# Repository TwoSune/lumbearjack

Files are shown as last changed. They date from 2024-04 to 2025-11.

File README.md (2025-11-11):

# Lumbearjack - Ortholinear 60% PCB based on Lumberjack by peej

Lumbearjack is a revision of peej's lumberjack with the following features:
* Pro Micro style controller support
* Per-key RGB and Backlight support
* Rotary encoder support
* SMD diode support
* BSS138 logic level shifter
  
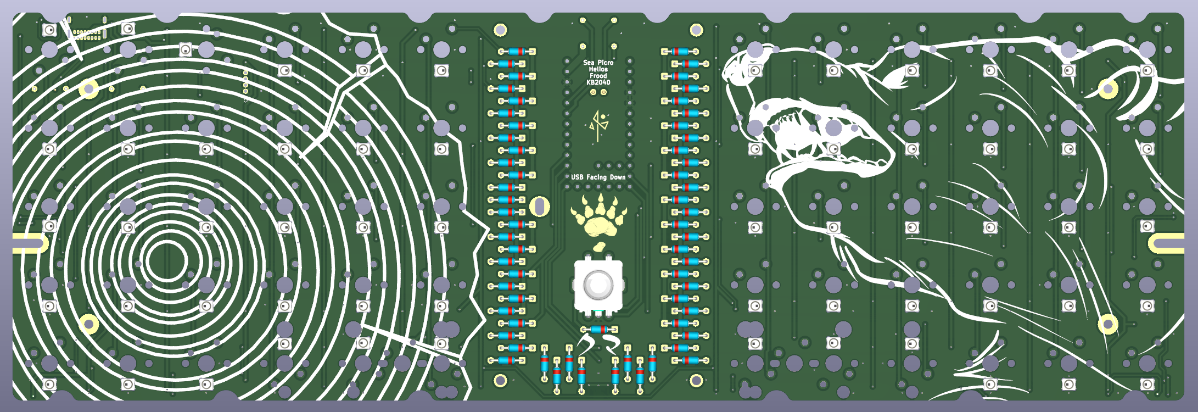
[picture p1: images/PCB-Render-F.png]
PCB Render Front

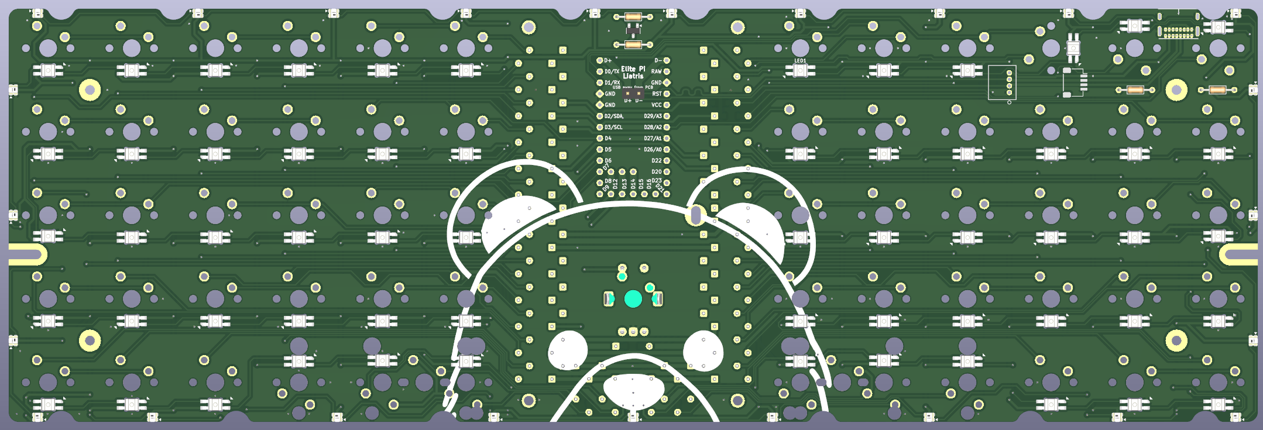
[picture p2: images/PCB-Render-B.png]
PCB Render Back


Lumbearjack is currently designed for the following development boards:
* Helios
* Sea Picro
* Frood
* KB2040 (no encoder support)
  
With support for the following, but you may struggle with external USB data lines
* Liatris
* Elite-Pi

At its core, Lumbearjack remains easy to build with minimal soldering experience, but being familiar with soldering is highly recommended for per-key RGB (SK68XX Mini-E) and backlight (WS2812B 2020).

Build Example
PCB Picture
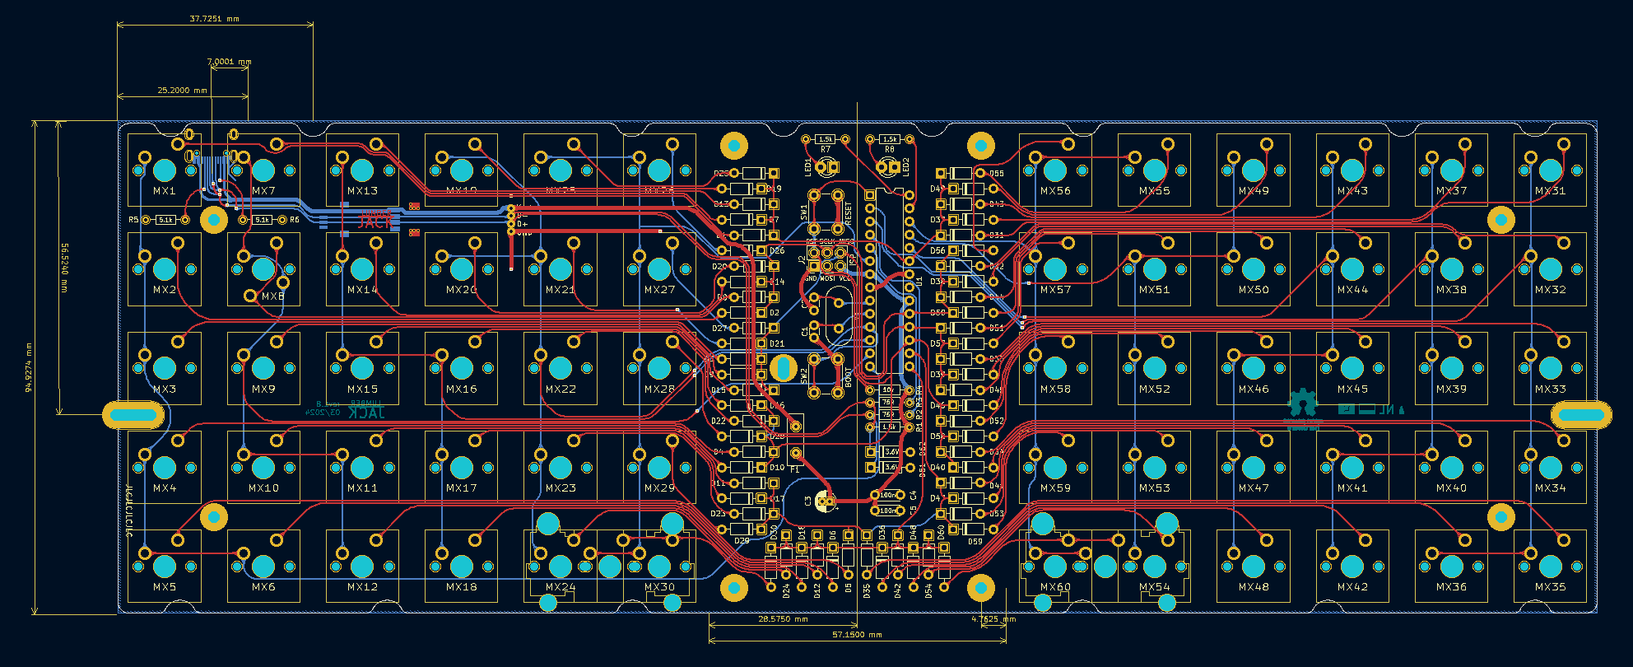
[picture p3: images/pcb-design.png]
PCB design


# Ordering parts

See the [Bill of materials](BOM.md) for a detailed list of the required parts.

BOM

PCBs can be manufactuered by a variety of online PCB fabricators. You can use [PCBShopper](https://pcbshopper.com/) to search for the best price.

The [zip file in the gerber directory](https://github.com/peej/lumberjack-keyboard/blob/master/gerber/lumberjack.zip) contains the gerber files your fabricator will need to make the PCB.

When uploading the gerber zip files, use the default PCB settings.

If you want to use a plate, there are [gerbers for FR4 plates](https://github.com/peej/lumberjack-keyboard/tree/smd-usbc/plates/gerbers). For the split plate, you will need two plates, one for each half of the keyboard.

# Construction

First, solder all the diodes on the top of the board. If you do not plan on using an encoder or a switch in the middle, you may omit the diode in the center of the board.
After you solder the diodes, solder the USB port on your board. From there, you may decide whether you would like to solder the LEDs or the controller to your board. It is recommended to solder the controller first so you may test your RGB as you solder them a few at a time.

See [the build guide](guide.md) for more information.

## Need help?

Feel free to create an issue request or contact me via discord at xsune for help!

# Firmware

Firmware is available in my [firmware repository](hyperlink)

Follow the [QMK firmware instructions](https://docs.qmk.fm/#/flashing) to build and flash the firmware.

(as of Rev 1.0, there is no onboard reset button. A reset button will be added to Rev 1.1.) 

## VIAL

Lumbearjack is compatible with Vial. You may follow the instructions for setting up a build environment [here](https://get.vial.today)
ZMK firmware will be added in the future

## Bootloader

 [See the build guide for more information](guide.md#bootloader).

## Matrix information

If you are building your own firmware, the following matrix information will be useful to you:

| Configuration | Value |
|---|---|
| MATRIX_ROWS | 12 |
| MATRIX_COLS | 7 |
| MATRIX_ROW_PINS | X (GPX), X (GPX), X (GPX), X (GPX), X (GPX), |
| MATRIX_COL_PINS | X (GPX), X (GPX), X (GPX), X (GPX), X (GPX), |
| DIODE_DIRECTION | COL2ROW |

Lumbearjack uses an interleaved matrix to save a pin for RGB and a pin for the middle key so KB2040 users may still have access to most of the features. You must use an Elite-C style dev board for encoder support.

Layout pins
# Component cover

Cut a piece of 2mm thick acrylic to size (95x57mm) and drill 4 m2 holes in the corners for the standoffs. Use the PCB or cover.dxf as a guide for the hole positions, you can also use cover.dxf for laser cutting the correct size acrylic.

Affix the 4 standoffs to the PCB with screws from underneath the PCB. Use the remaining 4 screws to attach the acrylic to the top of the standoffs.

Completed build w/o caps

# Revisions

## Rev 1.0

* Initial design introduced

## Rev 1.1 plans:
* Make external USB data lines easier to solder for Elite-Pi and Liatris users.
* RGB strip support
* Adjust some LED placements and switch orientations
* Add Reset Button
* Possibly revise the logic level shifter

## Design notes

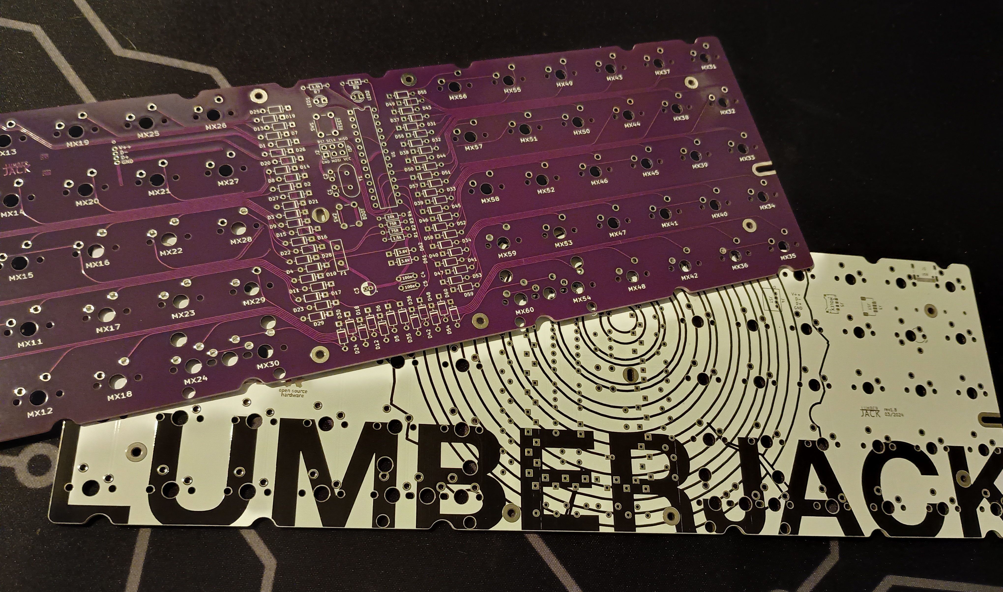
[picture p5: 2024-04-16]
images/pcb.jpg

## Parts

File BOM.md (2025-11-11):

# Bill of Materials (BOM)

| Ref | Qty | Value or Part# | Description |
|---|---|---|---|
| ![U1]() | 0-1 | Helios/n!n | Helios or similar controller with external USB |
| ![D1-61]() | 60-61 | 1N4148 | generic switching diode |
| ![MX1-61]() | 60-61 | MX Switch | Cherry MX-compatible keyboard switch |
| ![SW2]() | 0-1 | EC11 | EC11 rotary encoder (optional, instead of switch #61) |
| ![LED1-60]() | 60 | SK68XX MINI-E  | Per-key RGB (optional) |
| ![LED61-85]()  | 25 | WS2812 2020 | Backlight (optional) |
| ![LED61-85]()  | 25 | WS2812 Strip | Backlight (optional) |
| ![J1]() | 1 | USB4085-GF-A | USB-C socket (only used with the Frood controller) |
| ![J3]() | 1 | SM04B-SRSS-TB  | JST SH SMD socket, 1.5 mm pitch (optional for daughterboard) |
| ![J4]() | 1 | S4B-ZR | JST ZH right-angle THT socket, 1.5 mm pitch (optional for daughterboard) |
| ![R1, R2]() | 2 | 10 kΩ | 1/8 W resistor (For BSS138 Logic Level shifter) |
| ![R5, R6]() | 2 | 5.1 kΩ | 1/8 W resistor (only needed for USB-C) |
| ![SW1]() | 1 | 6x3 mm | tactile micro switch |
| ![cover]() | 1 | 95x57x3 mm | 3 mm acrylic component cover |
| ![screw]() | 8 | M2x4 mm | screws to mount the cover |
| ![standoff]()  | 4 | M2x10 mm | standoffs for component cover |

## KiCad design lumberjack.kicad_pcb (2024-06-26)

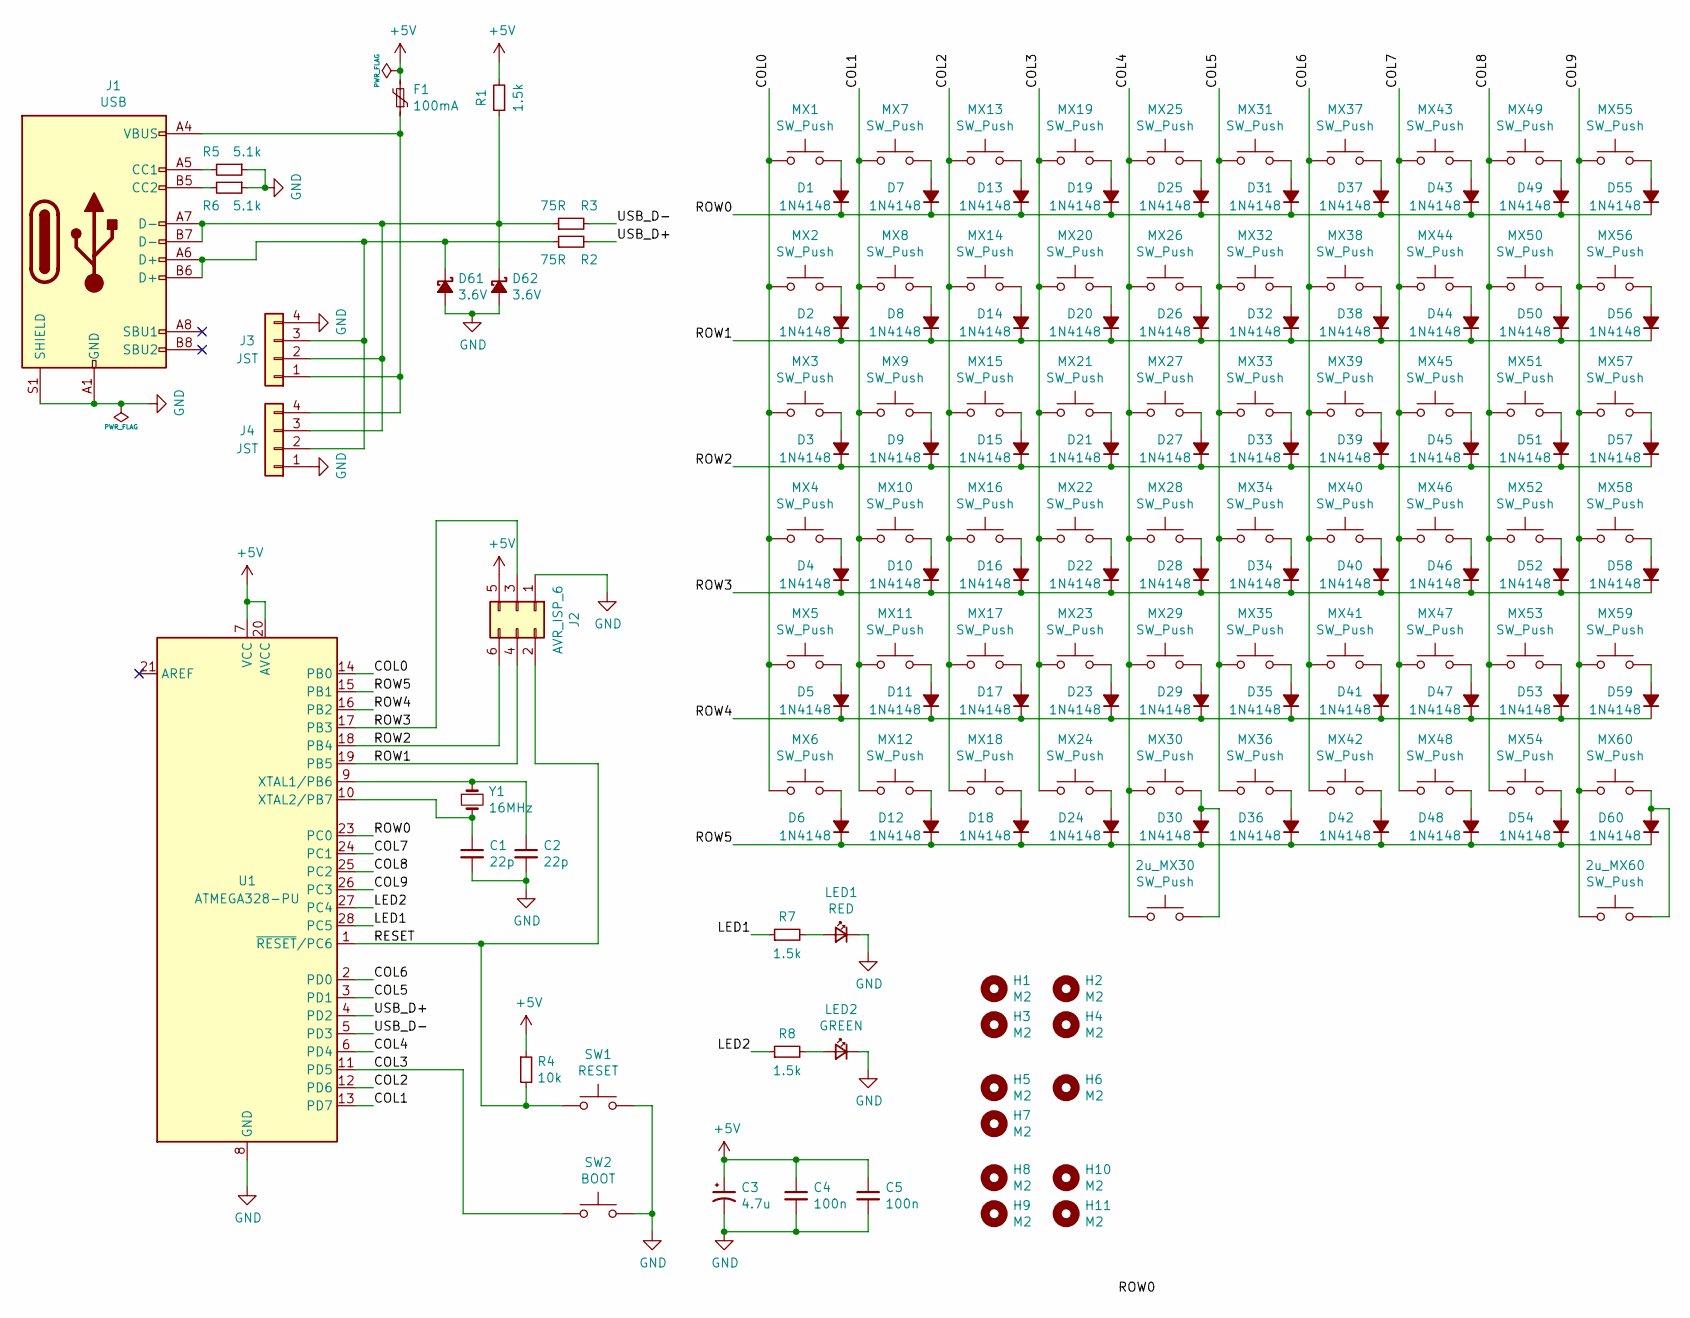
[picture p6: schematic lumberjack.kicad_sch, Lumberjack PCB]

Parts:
2u_MX30, 2u_MX60: SW_Push; MX_PCB_200B
C1, C2: 22p; C_Disc_D3.0mm_W1.6mm_P2.50mm
C3: 4.7u; CP_Radial_D4.0mm_P1.50mm
C4, C5: 100n; C_Disc_D4.3mm_W1.9mm_P5.00mm
D1, D2, D3, D4, D5, D6, D7, D8, D9, D10, D11, D12, D13, D14, D15, D16, D17, D18, D19, D20, D21, D22, D23, D24, D25, D26, D27, D28, D29, D30, D31, D32, D33, D34, D35, D36, D37, D38, D39, D40, D41, D42, D43, D44, D45, D46, D47, D48, D49, D50, D51, D52, D53, D54, D55, D56, D57, D58, D59, D60: 1N4148; D_DO-35_SOD27_P7.62mm_Horizontal
D61, D62: 3.6V; D_DO-35_SOD27_P7.62mm_Horizontal
F1: 100mA; Fuse_Bourns_MF-RHT100
H1, H2, H3, H4, H8, H9, H10, H11: M2; MountingHole_M2
H5, H6, H7: M2; MountingSlot_M2
J1: USB; TYPE-C-31-M-12
J2: AVR_ISP_6; PinHeader_2x03_P2.54mm_Vertical
J3: JST; JST_SH_SM04B-SRSS-TB_1x04-1MP_P1.00mm_Horizontal
J4: JST; S4B-ZRLFSN
LED1: RED; LED_D3.0mm
LED2: GREEN; LED_D3.0mm
MX1, MX2, MX3, MX4, MX5, MX6, MX7, MX9, MX10, MX11, MX12, MX13, MX14, MX15, MX16, MX17, MX18, MX19, MX20, MX21, MX22, MX23, MX24, MX25, MX26, MX27, MX28, MX29, MX30, MX31, MX32, MX33, MX34, MX35, MX36, MX37, MX38, MX39, MX40, MX41, MX42, MX43, MX44, MX45, MX46, MX47, MX48, MX49, MX50, MX51, MX52, MX53, MX54, MX55, MX56, MX57, MX58, MX59, MX60: SW_Push; MX_Alps_Choc
MX8: SW_Push; MX_Alps_Choc_NTHSTH
R1, R7, R8: 1.5k; R_Axial_DIN0204_L3.6mm_D1.6mm_P7.62mm_Horizontal
R2, R3: 75R; R_Axial_DIN0204_L3.6mm_D1.6mm_P7.62mm_Horizontal
R4: 10k; R_Axial_DIN0204_L3.6mm_D1.6mm_P7.62mm_Horizontal
R5, R6: 5.1k; R_Axial_DIN0204_L3.6mm_D1.6mm_P7.62mm_Horizontal
SW1: RESET; SW_PUSH_6mm
SW2: BOOT; SW_PUSH_6mm
U1: ATMEGA328-PU; DIP-28_W7.62mm
Y1: 16MHz; Crystal_HC49-4H_Vertical

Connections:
+5V: C3.1, C4.1, C5.1, F1.2, J2.5, R1.2, R4.1, U1.7 (VCC), U1.20 (AVCC)
/COL0: MX1.2, MX2.2, MX3.2, MX4.2, MX5.2, MX6.2, U1.14 (PB0)
/COL1: MX7.2, MX8.2, MX9.2, MX10.2, MX11.2, MX12.2, U1.13 (PD7)
/COL2: MX13.2, MX14.2, MX15.2, MX16.2, MX17.2, MX18.2, U1.12 (PD6)
/COL3: MX19.2, MX20.2, MX21.2, MX22.2, MX23.2, MX24.2, SW2.1, U1.11 (PD5)
/COL4: 2u_MX30.2, MX25.2, MX26.2, MX27.2, MX28.2, MX29.2, MX30.2, U1.6 (PD4)
/COL5: MX31.2, MX32.2, MX33.2, MX34.2, MX35.2, MX36.2, U1.3 (PD1)
/COL6: MX37.2, MX38.2, MX39.2, MX40.2, MX41.2, MX42.2, U1.2 (PD0)
/COL7: MX43.2, MX44.2, MX45.2, MX46.2, MX47.2, MX48.2, U1.24 (PC1)
/COL8: MX49.2, MX50.2, MX51.2, MX52.2, MX53.2, MX54.2, U1.25 (PC2)
/COL9: 2u_MX60.2, MX55.2, MX56.2, MX57.2, MX58.2, MX59.2, MX60.2, U1.26 (PC3)
/LED1: R7.1, U1.28 (PC5)
/LED2: R8.1, U1.27 (PC4)
/RESET: J2.2, R4.2, SW1.1, U1.1 (~RESET/PC6)
/ROW0: D1.1 (K), D7.1 (K), D13.1 (K), D19.1 (K), D25.1 (K), D31.1 (K), D37.1 (K), D43.1 (K), D49.1 (K), D55.1 (K), U1.23 (PC0)
/ROW1: D2.1 (K), D8.1 (K), D14.1 (K), D20.1 (K), D26.1 (K), D32.1 (K), D38.1 (K), D44.1 (K), D50.1 (K), D56.1 (K), J2.4, U1.19 (PB5)
/ROW2: D3.1 (K), D9.1 (K), D15.1 (K), D21.1 (K), D27.1 (K), D33.1 (K), D39.1 (K), D45.1 (K), D51.1 (K), D57.1 (K), J2.6, U1.18 (PB4)
/ROW3: D4.1 (K), D10.1 (K), D16.1 (K), D22.1 (K), D28.1 (K), D34.1 (K), D40.1 (K), D46.1 (K), D52.1 (K), D58.1 (K), J2.3, U1.17 (PB3)
/ROW4: D5.1 (K), D11.1 (K), D17.1 (K), D23.1 (K), D29.1 (K), D35.1 (K), D41.1 (K), D47.1 (K), D53.1 (K), D59.1 (K), U1.16 (PB2)
/ROW5: D6.1 (K), D12.1 (K), D18.1 (K), D24.1 (K), D30.1 (K), D36.1 (K), D42.1 (K), D48.1 (K), D54.1 (K), D60.1 (K), U1.15 (PB1)
/USB_D+: R2.2, U1.4 (PD2)
/USB_D-: R3.2, U1.5 (PD3)
GND: C1.2, C2.2, C3.2, C4.2, C5.2, D61.2 (A), D62.2 (A), J1.A1 (GND), J1.A12 (GND), J1.B1 (GND), J1.B12 (GND), J1.S1 (SHIELD), J2.1, J3.4, J4.1, LED1.1 (K), LED2.1 (K), R5.1, R6.1, SW1.2, SW2.2, U1.8 (GND), U1.22 (GND); also elsewhere on the board
unnamed: D1.2 (A), MX1.1
unnamed: D2.2 (A), MX2.1
unnamed: D3.2 (A), MX3.1
unnamed: D4.2 (A), MX4.1
unnamed: D5.2 (A), MX5.1
unnamed: D6.2 (A), MX6.1
unnamed: D7.2 (A), MX7.1
unnamed: D8.2 (A), MX8.1
unnamed: D9.2 (A), MX9.1
unnamed: D10.2 (A), MX10.1
unnamed: D11.2 (A), MX11.1
unnamed: D12.2 (A), MX12.1
unnamed: D13.2 (A), MX13.1
unnamed: D14.2 (A), MX14.1
unnamed: D15.2 (A), MX15.1
unnamed: D16.2 (A), MX16.1
unnamed: D17.2 (A), MX17.1
unnamed: D18.2 (A), MX18.1
unnamed: D19.2 (A), MX19.1
unnamed: D20.2 (A), MX20.1
unnamed: D21.2 (A), MX21.1
unnamed: D22.2 (A), MX22.1
unnamed: D23.2 (A), MX23.1
unnamed: D24.2 (A), MX24.1
unnamed: D25.2 (A), MX25.1
unnamed: D26.2 (A), MX26.1
unnamed: D27.2 (A), MX27.1
unnamed: D28.2 (A), MX28.1
unnamed: D29.2 (A), MX29.1
unnamed: 2u_MX30.1, D30.2 (A), MX30.1
unnamed: D31.2 (A), MX31.1
unnamed: D32.2 (A), MX32.1
unnamed: D33.2 (A), MX33.1
unnamed: D34.2 (A), MX34.1
unnamed: D35.2 (A), MX35.1
unnamed: D36.2 (A), MX36.1
unnamed: D37.2 (A), MX37.1
unnamed: D38.2 (A), MX38.1
unnamed: D39.2 (A), MX39.1
unnamed: D40.2 (A), MX40.1
unnamed: D41.2 (A), MX41.1
unnamed: D42.2 (A), MX42.1
unnamed: D43.2 (A), MX43.1
unnamed: D44.2 (A), MX44.1
unnamed: D45.2 (A), MX45.1
unnamed: D46.2 (A), MX46.1
unnamed: D47.2 (A), MX47.1
unnamed: D48.2 (A), MX48.1
unnamed: D49.2 (A), MX49.1
unnamed: D50.2 (A), MX50.1
unnamed: D51.2 (A), MX51.1
unnamed: D52.2 (A), MX52.1
unnamed: D53.2 (A), MX53.1
unnamed: D54.2 (A), MX54.1
unnamed: D55.2 (A), MX55.1
unnamed: D56.2 (A), MX56.1
unnamed: D57.2 (A), MX57.1
unnamed: D58.2 (A), MX58.1
unnamed: D59.2 (A), MX59.1
unnamed: 2u_MX60.1, D60.2 (A), MX60.1
unnamed 83: D61.1 (K), J1.A6 (D+), J1.B6 (D+), J3.3, J4.2, R2.1; also elsewhere on the board
unnamed 84: D62.1 (K), J1.A7 (D-), J1.B7 (D-), J3.2, J4.3, R1.1, R3.1; also elsewhere on the board
unnamed: J1.A5 (CC1), R5.2
unnamed: J1.B5 (CC2), R6.2
unnamed 87: F1.1, J1.A4 (VBUS), J1.A9 (VBUS), J1.B4 (VBUS), J1.B9 (VBUS), J3.1, J4.4; also elsewhere on the board
unnamed: LED1.2 (A), R7.2
unnamed: LED2.2 (A), R8.2
unnamed: C2.1, U1.9 (XTAL1/PB6), Y1.1
unnamed: C1.1, U1.10 (XTAL2/PB7), Y1.2

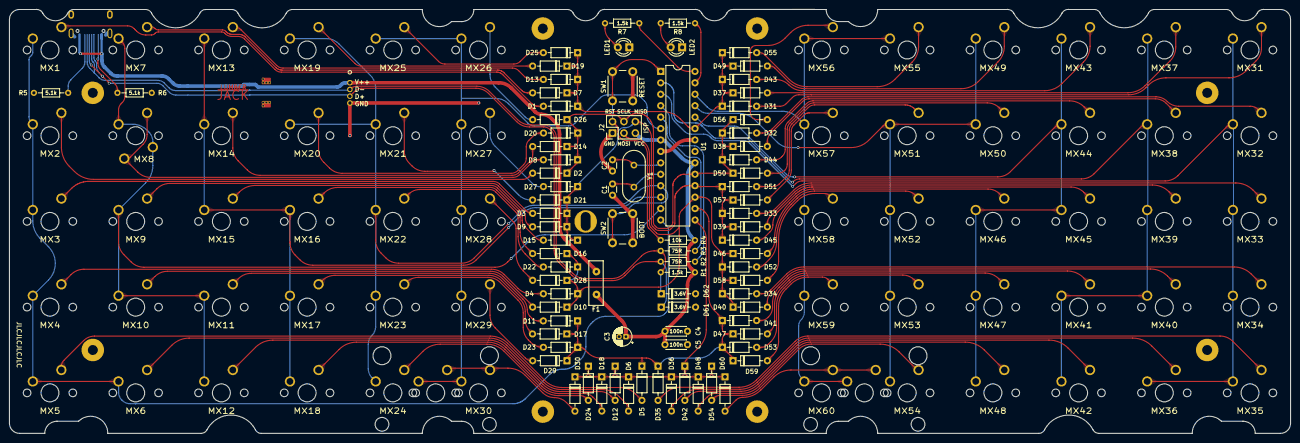
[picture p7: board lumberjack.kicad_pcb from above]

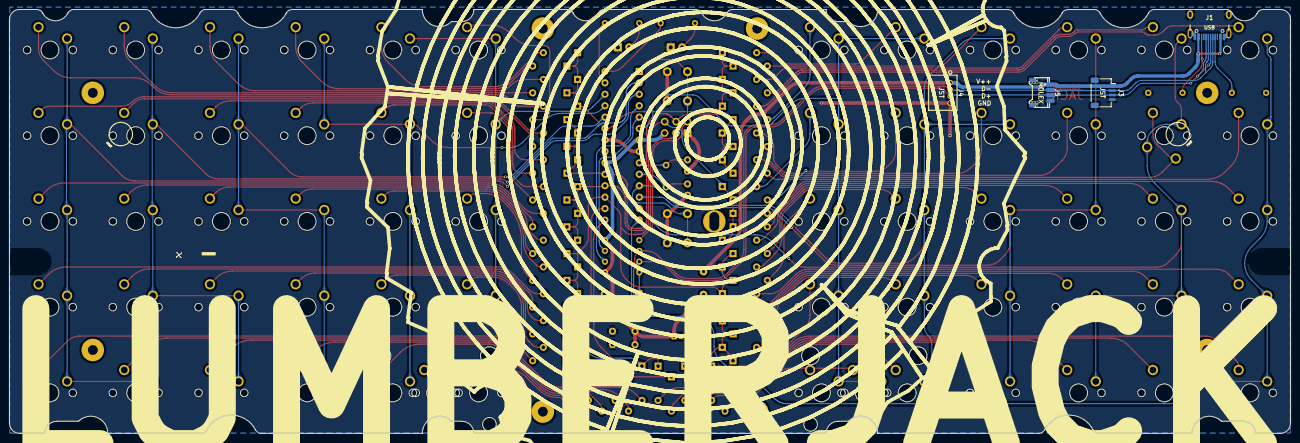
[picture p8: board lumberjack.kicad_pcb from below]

Board: 2 copper layers, 284.7 x 94.2 mm, 160 parts (4 on the bottom side), 92 nets.

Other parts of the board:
J5: Molex; PicoEZMate-Reinforced-Lite

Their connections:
GND: J5.4; also elsewhere on the board
unnamed 83: J5.3; also elsewhere on the board
unnamed 84: J5.2; also elsewhere on the board
unnamed 87: J5.1; also elsewhere on the board

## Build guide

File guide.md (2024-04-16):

# Lumberjack - Kit assembly guide

This assembly guide will guide you through putting together your Lumberjack keyboard PCB kit. The process is quite simple with only basic soldering experience.

## Before starting

* Check you have all the required items not included in the kit.
    * Soldering iron
    * Solder
    * Flush cutters
    * 60 MX key switches
* Check that you have all the components. See [BOM](BOM.md)
    * Keep the resistors in the paper reel so that it is easy to tell them apart based upon how many there are.
    * Do not confuse the 2 zener diodes with the 60 1N4148 diodes, they look almost identical but perform quite different functions.
* If you are not used to soldering, learn how to solder components.
    * https://learn.adafruit.com/adafruit-guide-excellent-soldering/tools

## Soldering

### USB connector (J1)
First you will solder the USB connector (or JST connector) to the **underside** of the PCB. All other components go on the top.

The connector is a surface mount device (SMD), meaning you will need to use a different soldering technique called drag soldering. You will need a separate supply of no-clean flux to do this, either liquid flux or a flux pen. Some isopropyl alcohol and a cotton bud is useful for cleaning up the flux residue afterwards.

* Tin the pads of the J1 footprint by adding a small amount of solder to each pad.
* Insert the USB connector into the board.
* Apply no-clean flux across all of the pads.
* Reheat the pads and press the USB port firmly into place to ensure it sits flat.
* The flux will cause the solder to flow to the pins and avoid creating solder bridges between the pins.
* Add more flux as needed as you go along.
* Use your iron between the pads to remove any solder bridges.
* Flip the board over and solder the legs into place.
* Check the solder joints carefully, under a magnifying glass if needed, to ensure there are no bridges between pads.

If you have a multimeter you can use it to check for bridges, put it into continuity mode and check that the following pins connect to each other and all others do not:

* Pins 1 & 12 are ground pins and should connect to each other and the ground pad of J4.
* Pins 2 & 11 are V+ pins and should connect to each other and the V+ pad of the J4.
* Pins 5 & 7 are D+ pins and should connect to each other and the D+ pad of the J4.
* Pins 6 & 8 are D- pins and should connect to each other and the D- pad of the J4.
* Pin 3 is the CC1 pin and should connect to the right pad of the R6 resistor only.
* Pin 9 is the CC2 pin and should connect to the left pad of the R5 resistor only.

#### JST connector (J3,4)

If you want to use a daughterboard instead of a USB connector, there are footprints for both a SMD or a THT connector. The connectors are positioned between the top and second row of switches so as to fall within the cable gutter of cases such as the Bakeneko, be aware that this might not be a suitable position for all cases.

Note: A JST connector is not included in the Lumberjack kit, the SMD variant is part JST-SR-4 and for THT it is S4B-ZR.

### Zener diodes (D61,62)

Solder the Zener diodes D61 and D62 (D66 and D67 in older PCB revisions).

Diodes are a polarized component and therefore take care of direction, the black line on the diode is the cathode and goes in the square pad on PCB.

Do not get these confused with the 1N4148 diodes.

Zener diodes

### Resistors (R1,2,3,4,7,8)

Solder the resistors.

Ensure you use the correct size resistor for the correct position. You can identify which resistors are which due to the number of resistors of each type in the kit or by matching the colored bands on the resistors.

* R1,7,8: 1.5kΩ Brown, green, black, brown, red
* R2,3: 75Ω Violet, green, black, gold, red
* R4: 10kΩ Brown, black, black, red, red

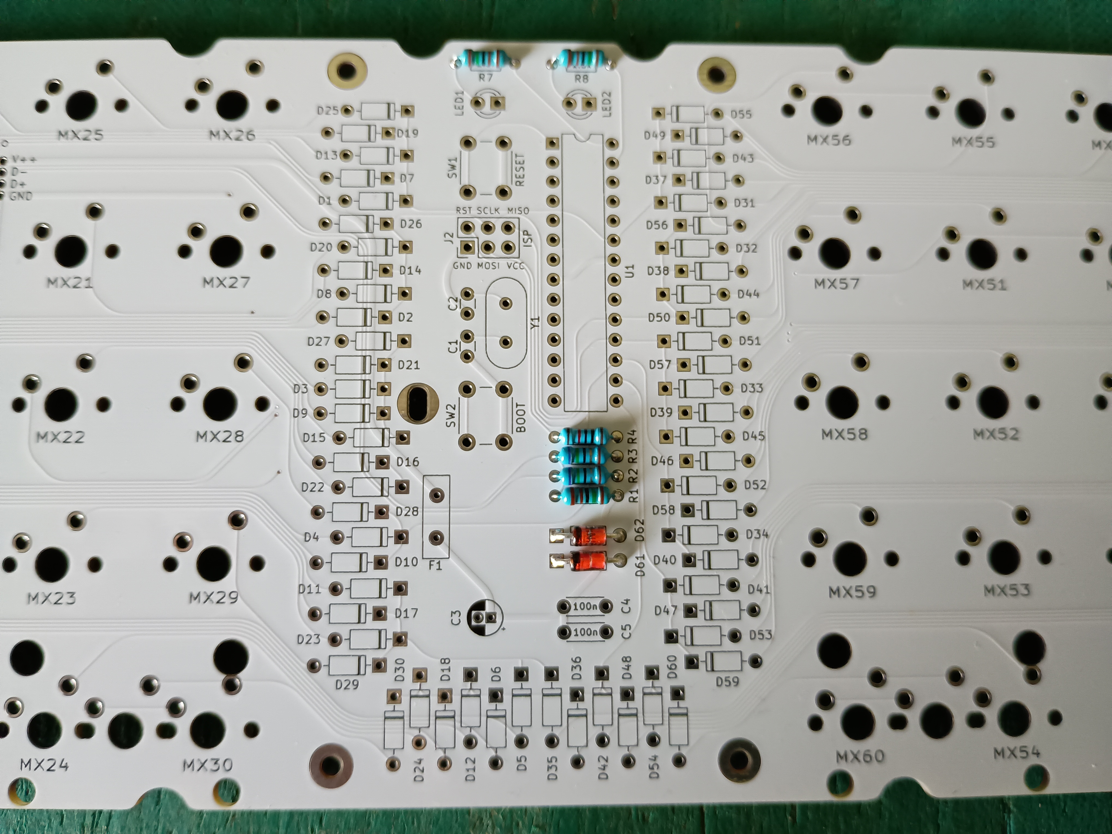
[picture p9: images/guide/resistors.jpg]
Resistors


### Resistors for USB-C (R5,6)

The USB-C connector requires two more resistors. They are marked in the kit with a black dot on the paper to help distingish them from the other resistors.

* R5,6: 5.1kΩ Green, brown, black, brown, red

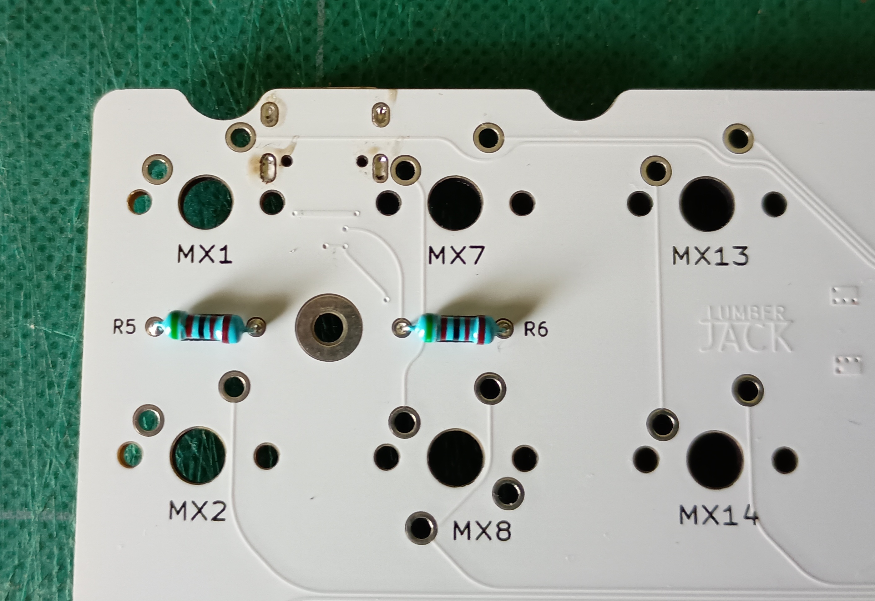
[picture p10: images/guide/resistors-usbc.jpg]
USB-C resistors


### Diodes 1N4148 (D1-60)

Solder the diodes.

Diodes are a polarized component and therefore take care of direction, the black line on the diode is the cathode and goes in the square pad on PCB.

1N4148 diodes

### Crystal (Y1)

Solder the crystal.

Crystal

### Capacitors (C1,2,4,5)

Solder the small brown (or yellow) 22pF capacitors C1 and C2 (marked 22).

Solder the small yellow 100nF capacitors C4 and C5 (marked 104).

Do not get the two sets of capacitors confused. Depending on the pitch of the capacitors, you might need to bend the legs so that they fit into the pads.

Capacitors

Leave C3 until later as it is tall and will stop the PCB from laying flat making the other steps harder.

### LEDs (LED1,2)

Solder the LEDs.

LEDs are a polarized component and therefore take care of direction, the short leg is the cathode and goes in the square pad on PCB.

LEDs

### IC socket (U1)

Solder on the IC socket. 

The IC socket mounts a polarized component, check the notch on silkscreen and IC Socket.

IC Socket

Do not insert microcontroller into the socket before soldering the socket to the PCB.

### Electrolytic capacitor (C3)

Electrolytic capacitor is a polarized component, the short leg is the cathode and goes in the circular (left) pad on PCB (nearest the C3 marking).

The soldermask around the pads can cause confusion as to which pad is which. The circular pad has a white square pattern around it making it look like it is square, so be careful and double check. The capacitor should be orientated so that the side with the line on it is on the left.

Capacitor

To fit under the component cover, ensure that your capacitor body is less than 10mm tall.

If your capacitor is taller than 10mm and will not fit under the component cover, you can alternatively bend the legs and lie the capacitor down into the empty space on the PCB above the pad.

Tall capacitor

### Resettable fuse (F1)

Solder on the resettable fuse.

After soldering, bend the fuse over to that it lays flat on the PCB.

Fuse

If you have placed the capacitor into the empty space that the fuse would usually occupy, straighten the legs of the fuse with pliers before soldering it so that it can be soldered lower into the PCB.

### Tactile switches (SW1,2)

Push the switches into the PCB and solder the legs.

Push switches

### ISP header (J2)

Used for programming the microprocessor with the bootloader directly. If your MCU is already programmed you can skip adding this header if you want.

ISP header

### ATMEGA328P (U1)

Insert ATMEGA328P into IC Socket.

You will probably need to carefully bend the legs to make it fit into the socket. Take care and gently bend them against a flat surface until they are spaced correctly for the socket.

Ensure that you insert it in the correct orientation, the semicircular mark should match that of the silkscreen.

Take care that all the legs go into the socket correctly and do not get accidently bend outside of the socket. The end legs are small and fragile, repeated bending of the legs can cause them to break off.

ATMEGA328P

### Check list

Before connecting the board to your computer, a few things to double check just to be safe:

* Take a close look at the USB connector pins and visually check there is no short between the VCC and GND pins. If you have a multimeter, now might be a good time to use it.
* Check the orientation of polarized components (ATMEGA328p, diode, electrolytic capacitor).
* Double check the correct resistor values are in the correct locations.

## Software

Note: If you got your Lumberjack as a kit, the microprocesor is already flashed with a bootloader and firmware, and you can skip this and the firmware steps.

### Bootloader

A bootloader is a piece of software on the microprocessor which can be used to flash firmware onto the microprocessor and to pass execution control to that firmware.

You will need to flash the microprocessor with a bootloader. To do this you will need another device which can be connected to the ISP headers and used to flash the bootloader to the chip. Since Lumberjack is the same as the Plaid, we can use the same bootloader.

* Download the [Plaid bootloader](https://github.com/hsgw/USBaspLoader/tree/plaid) and follow the instructions to compile the bootloader.
* Follow the [QMK ISP flashing guide](https://docs.qmk.fm/#/isp_flashing_guide) to get the bootloader onto the chip.

Don't forget to set the fuses: low `0xd7`, high `0xd0`, extended `0xfc`.

There is a pre-compiled bootloader + firmware in the [bootloader directory](bootloader) along with an example `avrdude` command for flashing it.

### Firmware

Follow the [QMK firmware instructions](https://docs.qmk.fm/#/flashing) to build and flash the firmware.

`qmk flash -kb peej/lumberjack`

To put the board into bootloader mode so it is ready to recieve firmware, press and hold the BOOT button (SW2) while pressing and releasing the RESET button (SW1). The board will now be detected as an USBasp device and can have the firmware flashed via the USB port.

Pressing the RESET button (SW1) on its own will restart the microprocessor. Once flashed with firmware it is neccessary to reset the keyboard so as to return control to the new firmware.

Note that due to the BOOT button (SW2) sharing a pin with column 3, when pressed the keys in that column will also activate. This is expected behavour but can be a little annoying or confusing if you are not expecting it.

### Can't recognize bootloader

* Check components and soldering near ATMEGA328p.
    * Direction of ATMEGA328p
    * BOOT SW and RESET SW
    * USB connector
    * R1, R2, R3, D66, D67
* Try different USB cable, PC, USB hub
    * If you connect via USB hub, try connecting directly.

### Check list

Now the board should be fully functional, so check that everything works before adding the switches.

Plug in the PCB and use a pair of tweazers or a piece of wire to check each keyswitch pad triggers a keypress.

## Switches

### Stabilizers

If you are using 2u keys and want to use key stabilizers, fix them to the board before inserting the switches.

If you are using screw in stabilizers, be aware that the screws can cause a short to the unused switch pads for the 1u keys. To avoid this, use plastic washers or electrical tape under the screws to isolate them from the PCB.

### Trim switch legs

When fitting key switches, the switches at the 'Q' and 'P' positions on the 2nd row will fowl on the standoffs in your keyboard case, so you need to trim down one of the stabilizing pins and part of the center pin to ensure the PCB fits flush within the case.

Switch legs

If you are using a 2u key on the right hand side, you will also need to trim down the center pin so that it does not fowl on the standoff. The position the case standoffs will be is marked on the soldermask of the underside of the PCB.

Switch center pin

### Insert switches

Insert the switches into the PCB and solder the pins of each switch.

If you are using a plate, insert the switches into the plate first and then insert into the PCB.

Ensure that the switch is fully inserted and sitting flush with the PCB before soldering.

Note also that the switch at the 'Q' position is upsidedown so that the switch pins do not interfere with the case standoffs.

## Component cover

Affix the 4 standoffs to the PCB with screws from underneath the PCB. Use the remaining 4 screws to attach the acrylic to the top of the standoffs.

Do not overtighten the screws as this could crack the acrylic.

## Case fitting

When fixing the PCB to your case you will only use the center, the left and the right screw holes. Depending on your case design, the PCB will be supported by the other standoffs.

## End

Congratulations, your build is complete.

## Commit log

2024-04-16 Add Molex connector footprint
    [lumberjack.kicad_pcb, lumberjack.kicad_sch]
2024-04-16 Update gerber files
    [lumberjack-B_Cu.gbr, lumberjack-B_Mask.gbr, lumberjack-B_Paste.gbr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]
2024-04-16 Move USB footprint closer to end of board
    [lumberjack.kicad_pcb]
2024-06-26 Add H60 compatible edge cutouts
    [lumberjack.kicad_pcb]
2025-09-28 Switch to SMD USB-C connector
    [lumberjack-B_Cu.gbr, lumberjack-B_Mask.gbr, lumberjack-B_Paste.gbr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]
2025-09-28 Remove top copper layer and fillet traces

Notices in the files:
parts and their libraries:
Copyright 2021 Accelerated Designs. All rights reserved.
